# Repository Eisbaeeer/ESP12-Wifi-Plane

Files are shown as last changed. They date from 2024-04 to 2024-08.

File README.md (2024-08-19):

# VIMANA-STEM-LIGHT
The LIGHT version works with the prior ESP12E/ESP12F or other ESP8266 controllers.
This project is a fork without the need of N76E003. The main features is to use the controls of the new app to control two motors and servos.
You can use the unused ports to controll additional servos (not yet implemented).
If you need more, feel free to contribute.
Thank you to Ravi for his work.

You will find the Anrdoid App in the folder Andorid.

The Original Github repo for VIMANA2 Opensource Flightcontroller Board for Tiny Smartphone controlled Air plane and other moving/flying/floating things you will find on following links.
<br>Suitable for STEM Education<br>
Project Documentation : https://hackaday.io/project/190462-vimana-stem-for-all <br>
Youtube Playlist : https://www.youtube.com/playlist?list=PL6rHZ-FYvZtEZ2F3nPtqbe_Y3SMQ8Gjly <br>

## Features
- fully compatible to the first release of Ravis hardware
- supports two motors
- sending RSSI to mobile device
- sending battery voltage of receiver to mobile device
- calibrate motors
- update firmware via OTA http://192.168.43.42/update

## Schematic

| Board Pins | | Device Pin | Device Name | 
|---|-----|---|---|
| GPIO 04 | G | Gain | Motor right Si2302DS | 
| GPIO 05 | G | Gain | Motor left Si2302DS | 

## Folders

- CAD --> Plane cutouts for laser or cnc or by hand and pdf paper  
- Gerber --> Gerber files for PCB   
- src --> Source files for Platformio

## Flashing firmware

To flash the board, use UART to USB adapter. Do it in this step´s to enable flashing mode of ESP
1. Connect the pins to the UART adapter (GND, TX, RX)   
2. Connect E-pin to GND
3. Plug in the battery
4. Flash the ESP

## Updating firmware

The firmware includes OTA (Over-The-Air Update).
You can easily upload the compiled firmware file (firmware.bin) via web-browser.
Connect to the Wifi accesspoint of the plane, open the browser and type in the following url.
http://192.168.43.42/update

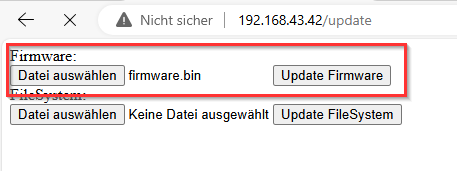
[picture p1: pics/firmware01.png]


Click on select file and upload the firmware (this takes some seconds). The click on Update Firmware.

## ToDo
- adding pins D1 (GPIO5), D2 (GPIO4), GND, VCC  (for future use of MPU6050)
- adding pins GPIO12, GND, VCC (Servo elevator)
- adding pins GPIO13, GND, VCC (Servo ruder)

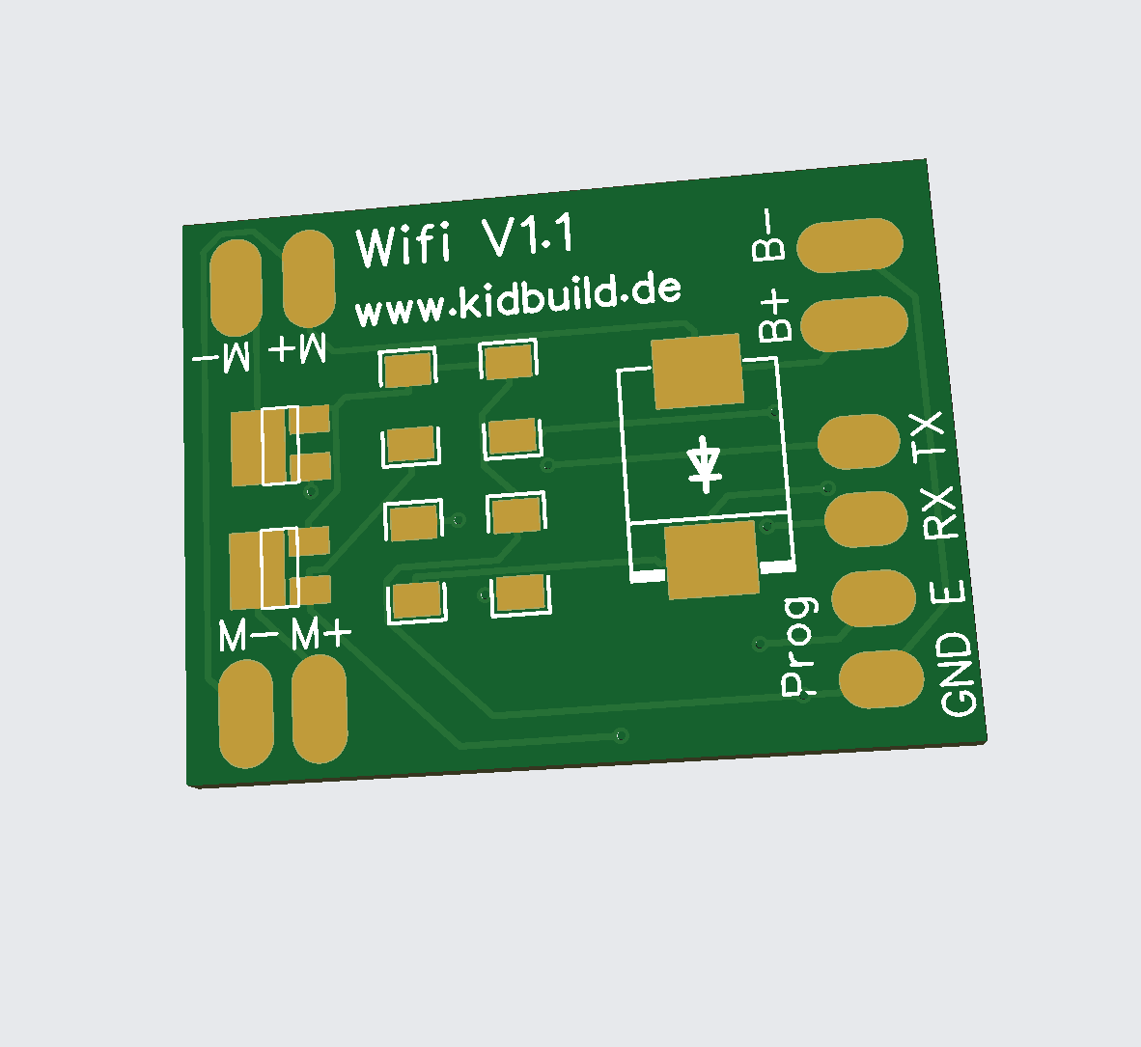
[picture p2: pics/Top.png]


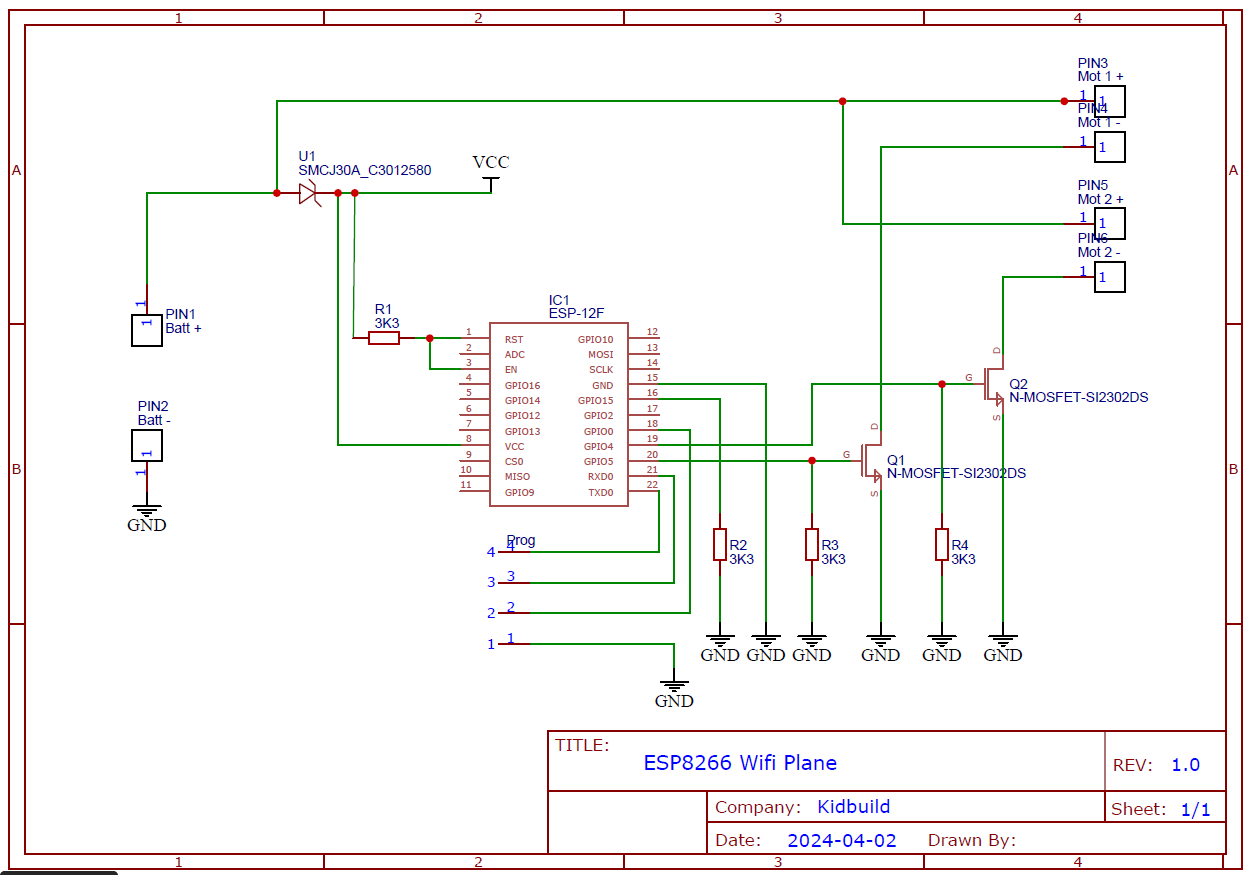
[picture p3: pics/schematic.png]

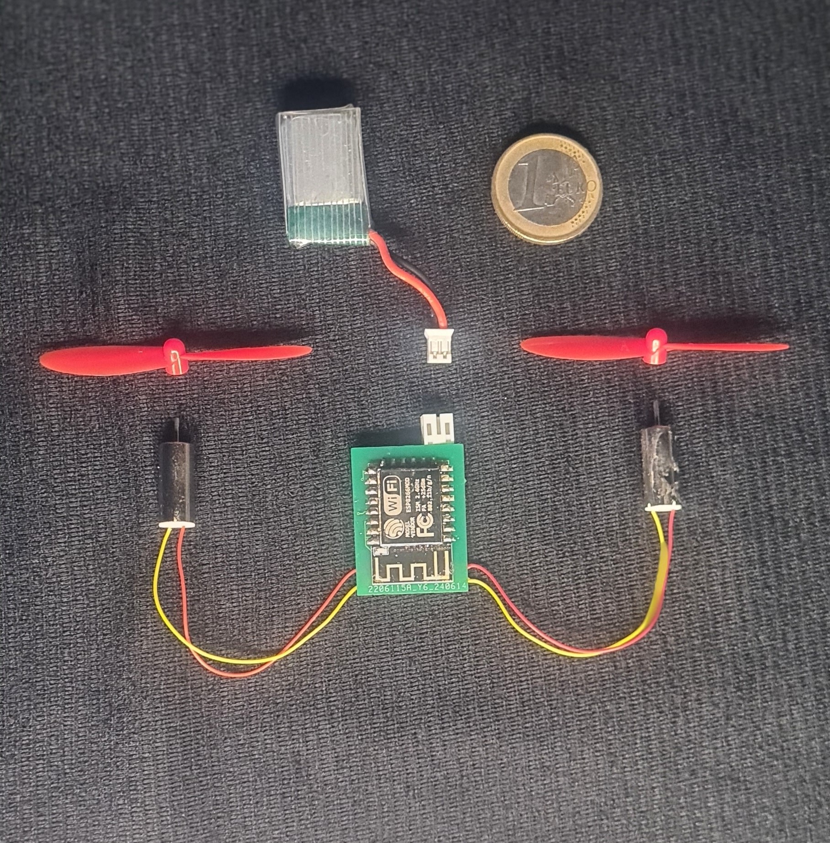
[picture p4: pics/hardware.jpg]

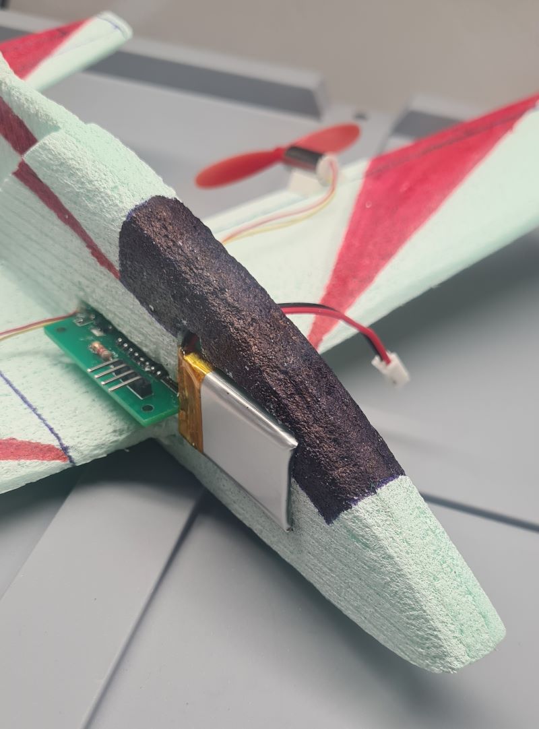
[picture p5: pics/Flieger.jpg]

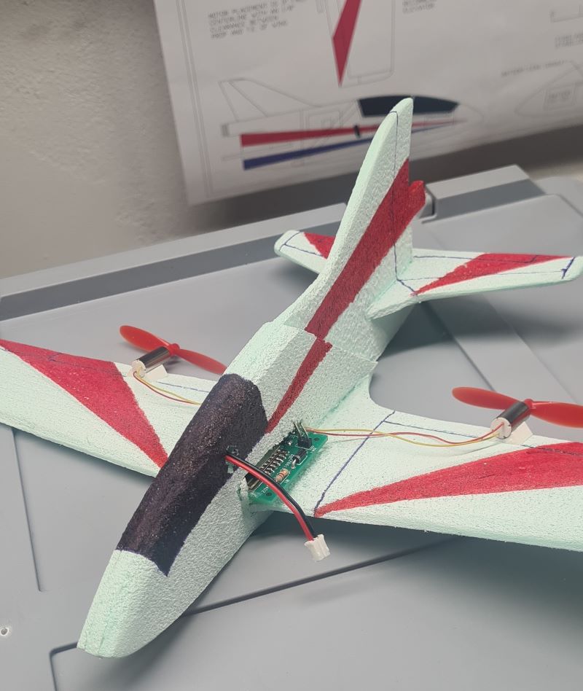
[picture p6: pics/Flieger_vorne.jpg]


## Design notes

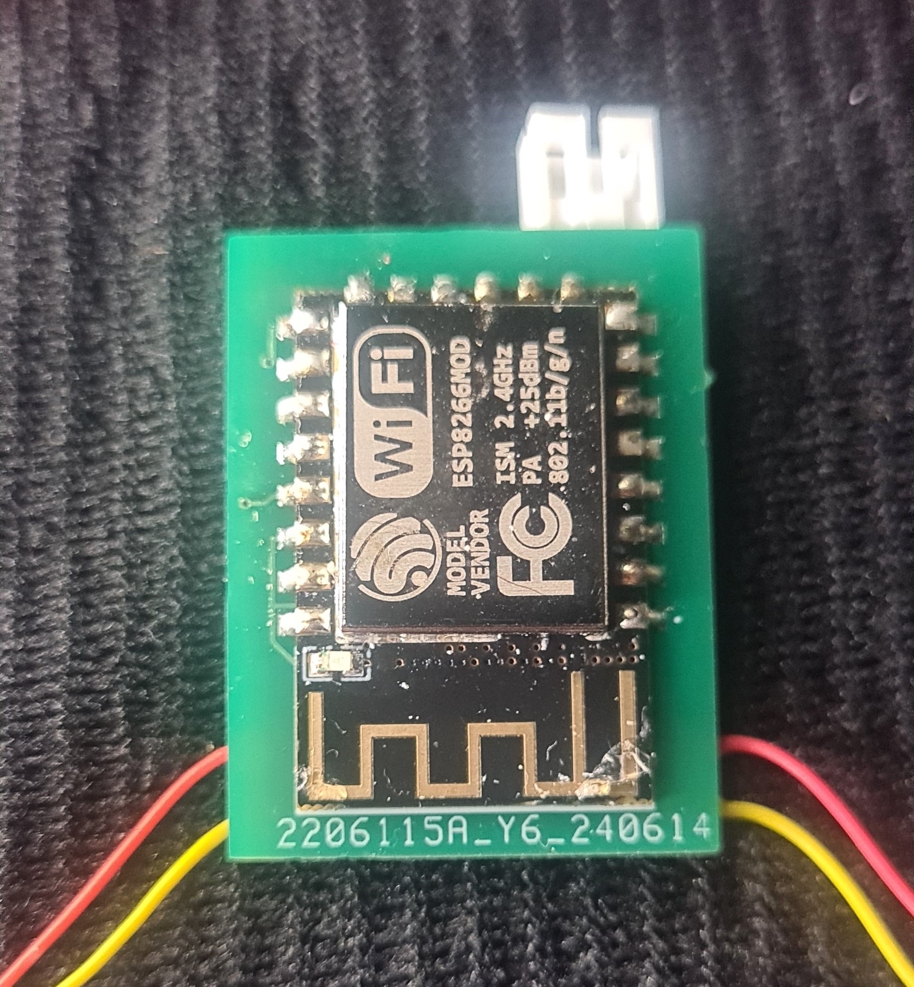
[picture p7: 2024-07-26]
pics/bottom.jpg

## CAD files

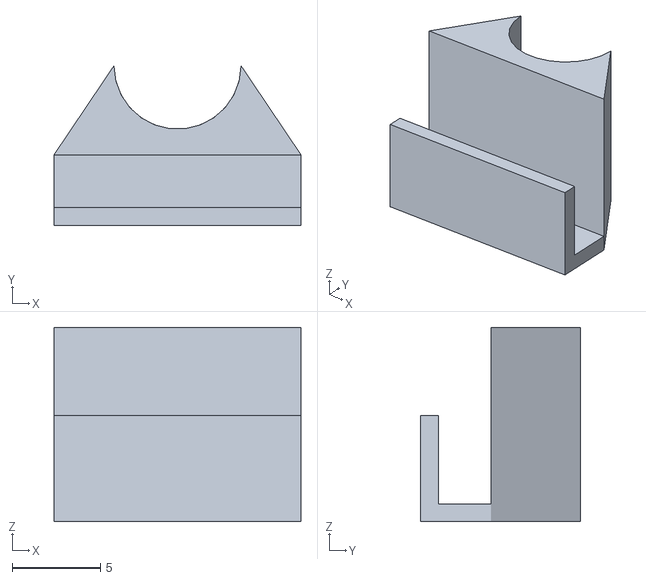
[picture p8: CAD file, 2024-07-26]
CAD/Motorblock_3mm_Depron.stl
14.0 x 9.05 x 11.0

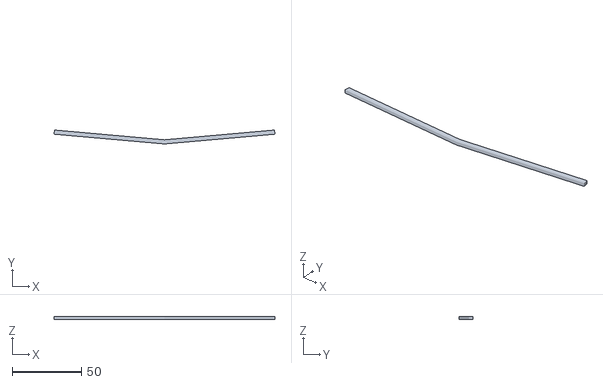
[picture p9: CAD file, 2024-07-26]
CAD/FluegelWinkel_3mm_Depron.stl
159.4 x 10.0 x 2.00

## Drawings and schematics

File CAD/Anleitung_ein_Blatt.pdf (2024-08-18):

# Wifi Controlled Park Flyer

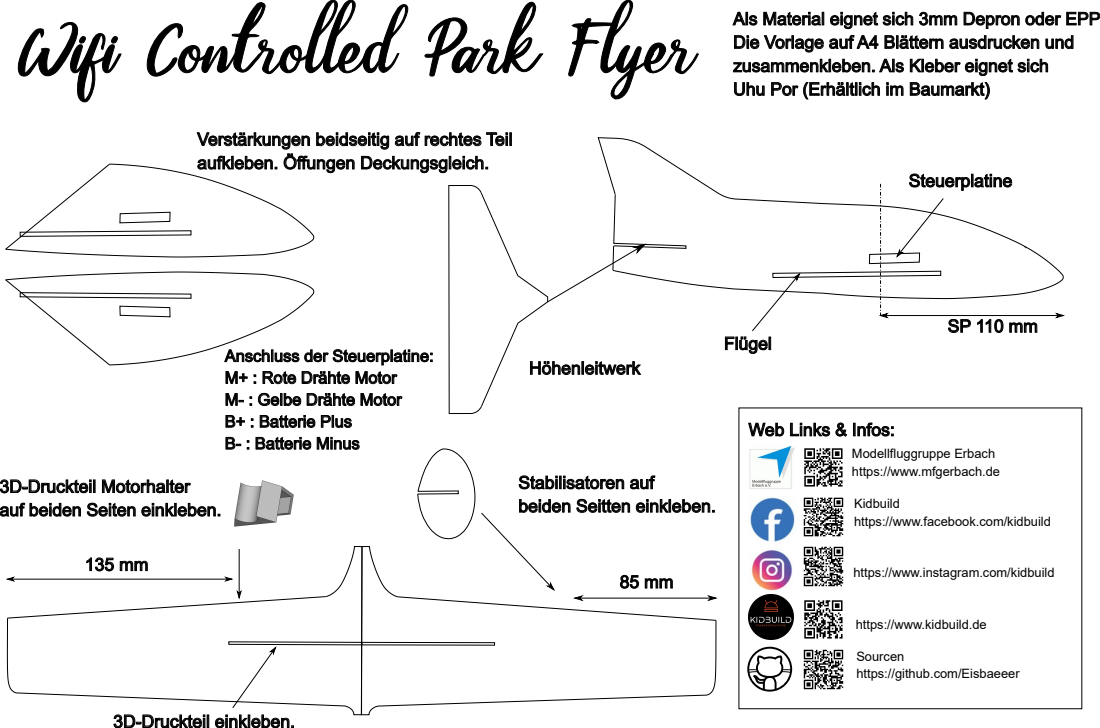
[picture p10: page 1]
Flügel; Höhenleitwerk; 3D-Druckteil einkleben.; Steuerplatine

Als Material eignet sich 3mm Depron oder EPP
Die Vorlage auf A4 Blättern ausdrucken und
zusammenkleben. Als Kleber eignet sich
Uhu Por (Erhältlich im Baumarkt)

Verstärkungen beidseitig auf rechtes Teil
aufkleben. Öffungen Deckungsgleich.

Anschluss der Steuerplatine:
M+ : Rote Drähte Motor
M- : Gelbe Drähte Motor
B+ : Batterie Plus
B- : Batterie Minus

Web Links & Infos:

Modellfluggruppe Erbach
https://www.mfgerbach.de

Stabilisatoren auf
beiden Seitten einkleben.

3D-Druckteil Motorhalter
auf beiden Seiten einkleben.

Kidbuild
https://www.facebook.com/kidbuild

https://www.instagram.com/kidbuild

https://www.kidbuild.de

Sourcen
https://github.com/Eisbaeeer

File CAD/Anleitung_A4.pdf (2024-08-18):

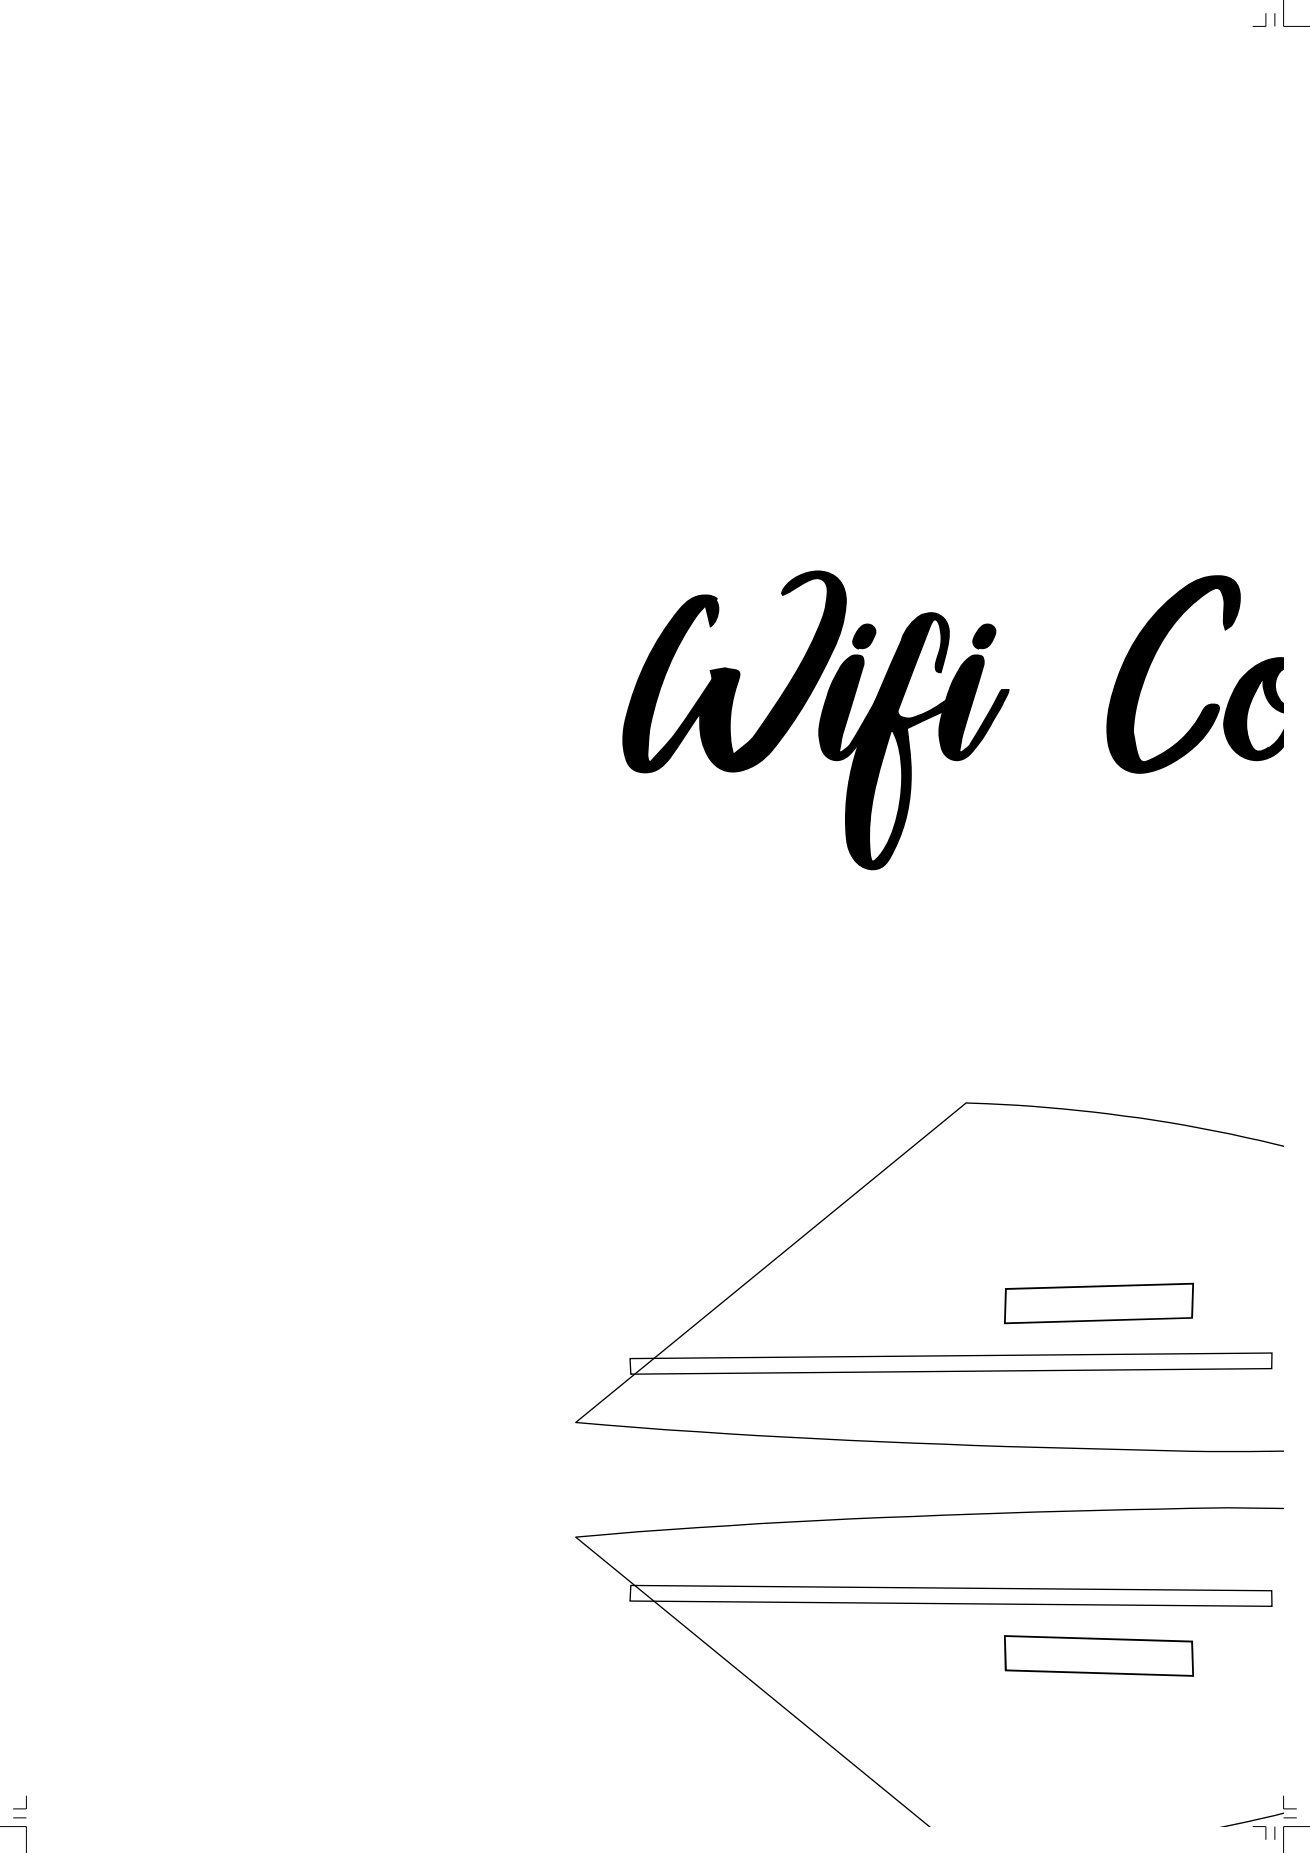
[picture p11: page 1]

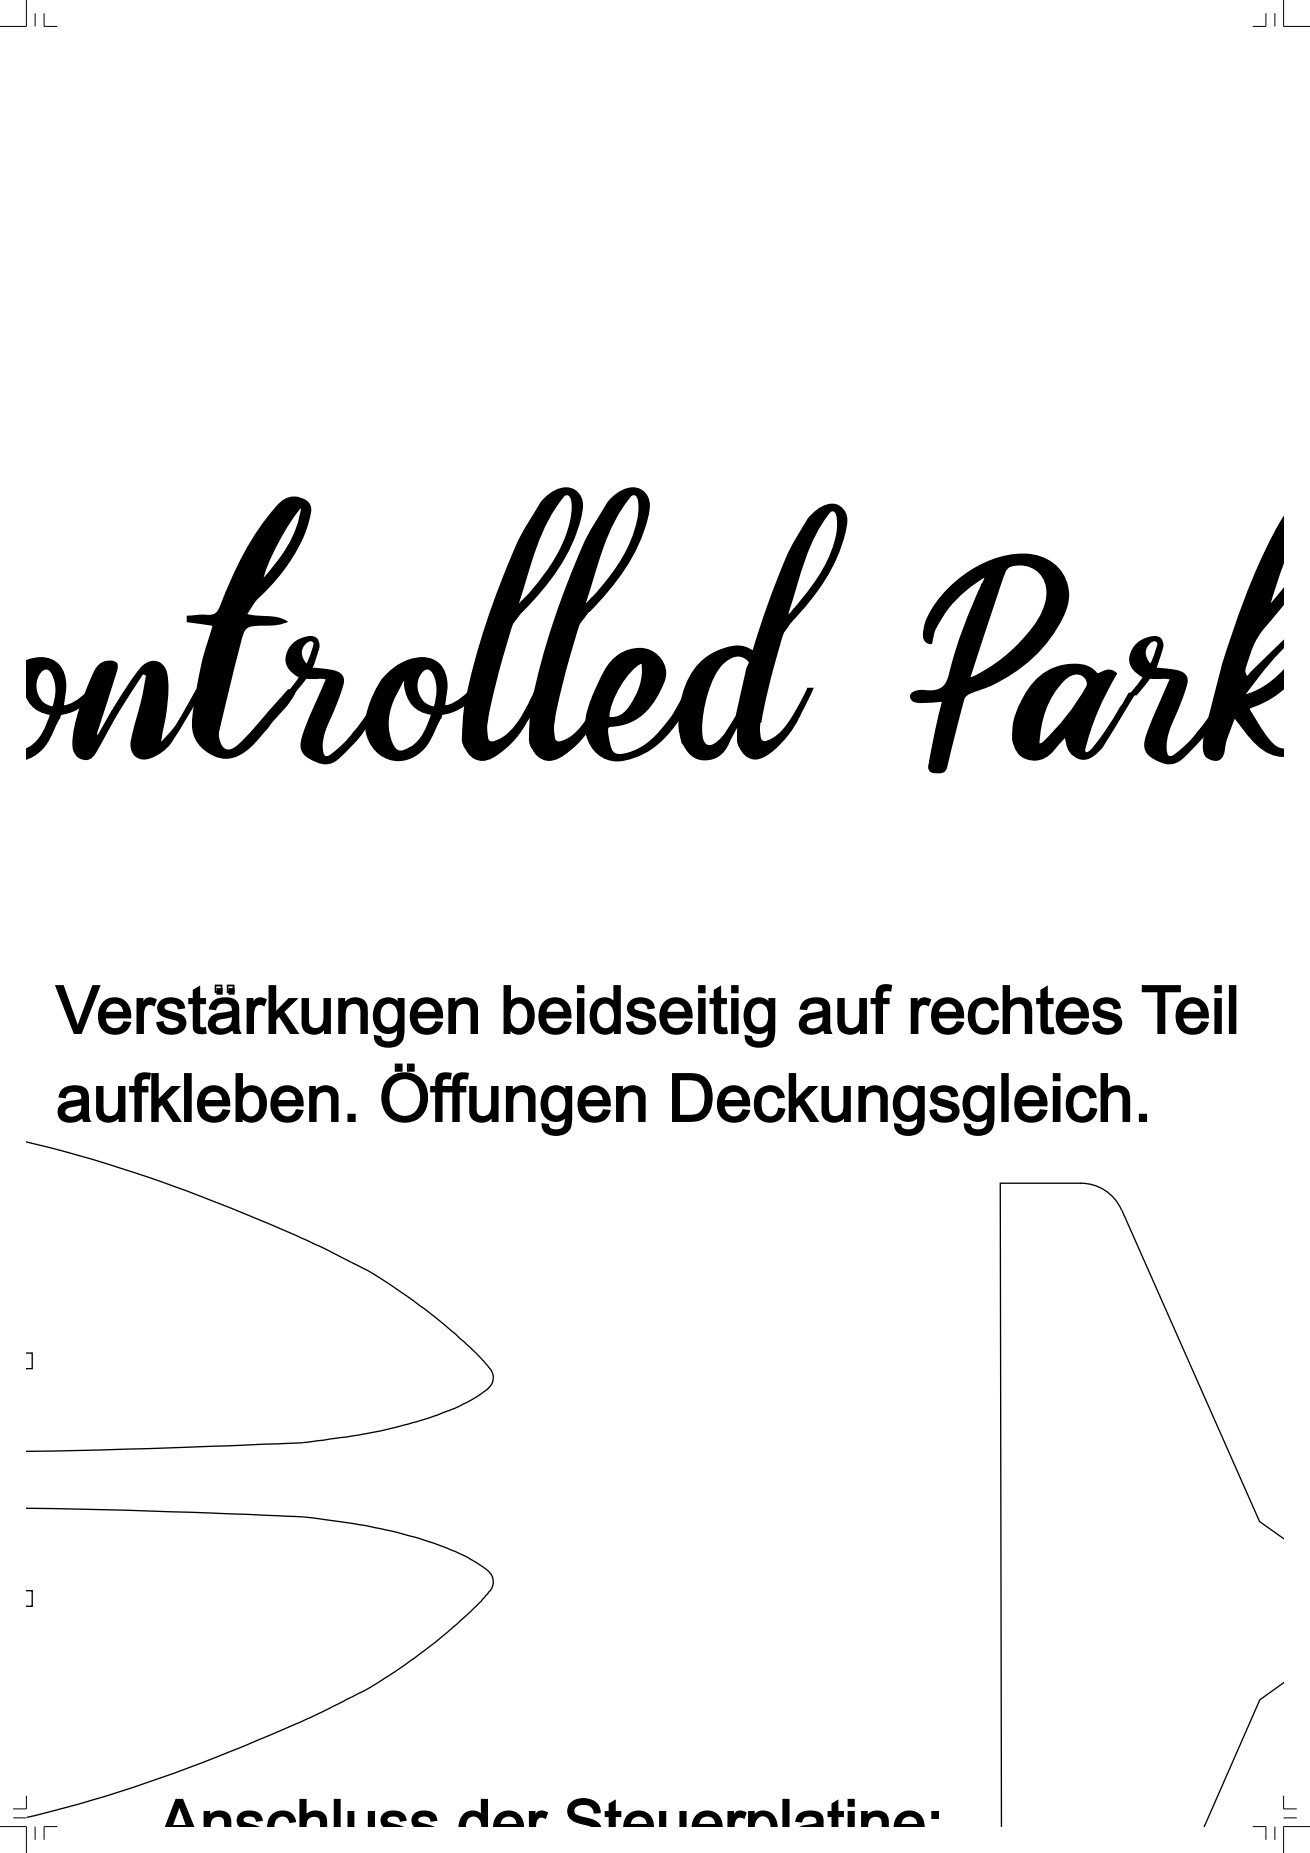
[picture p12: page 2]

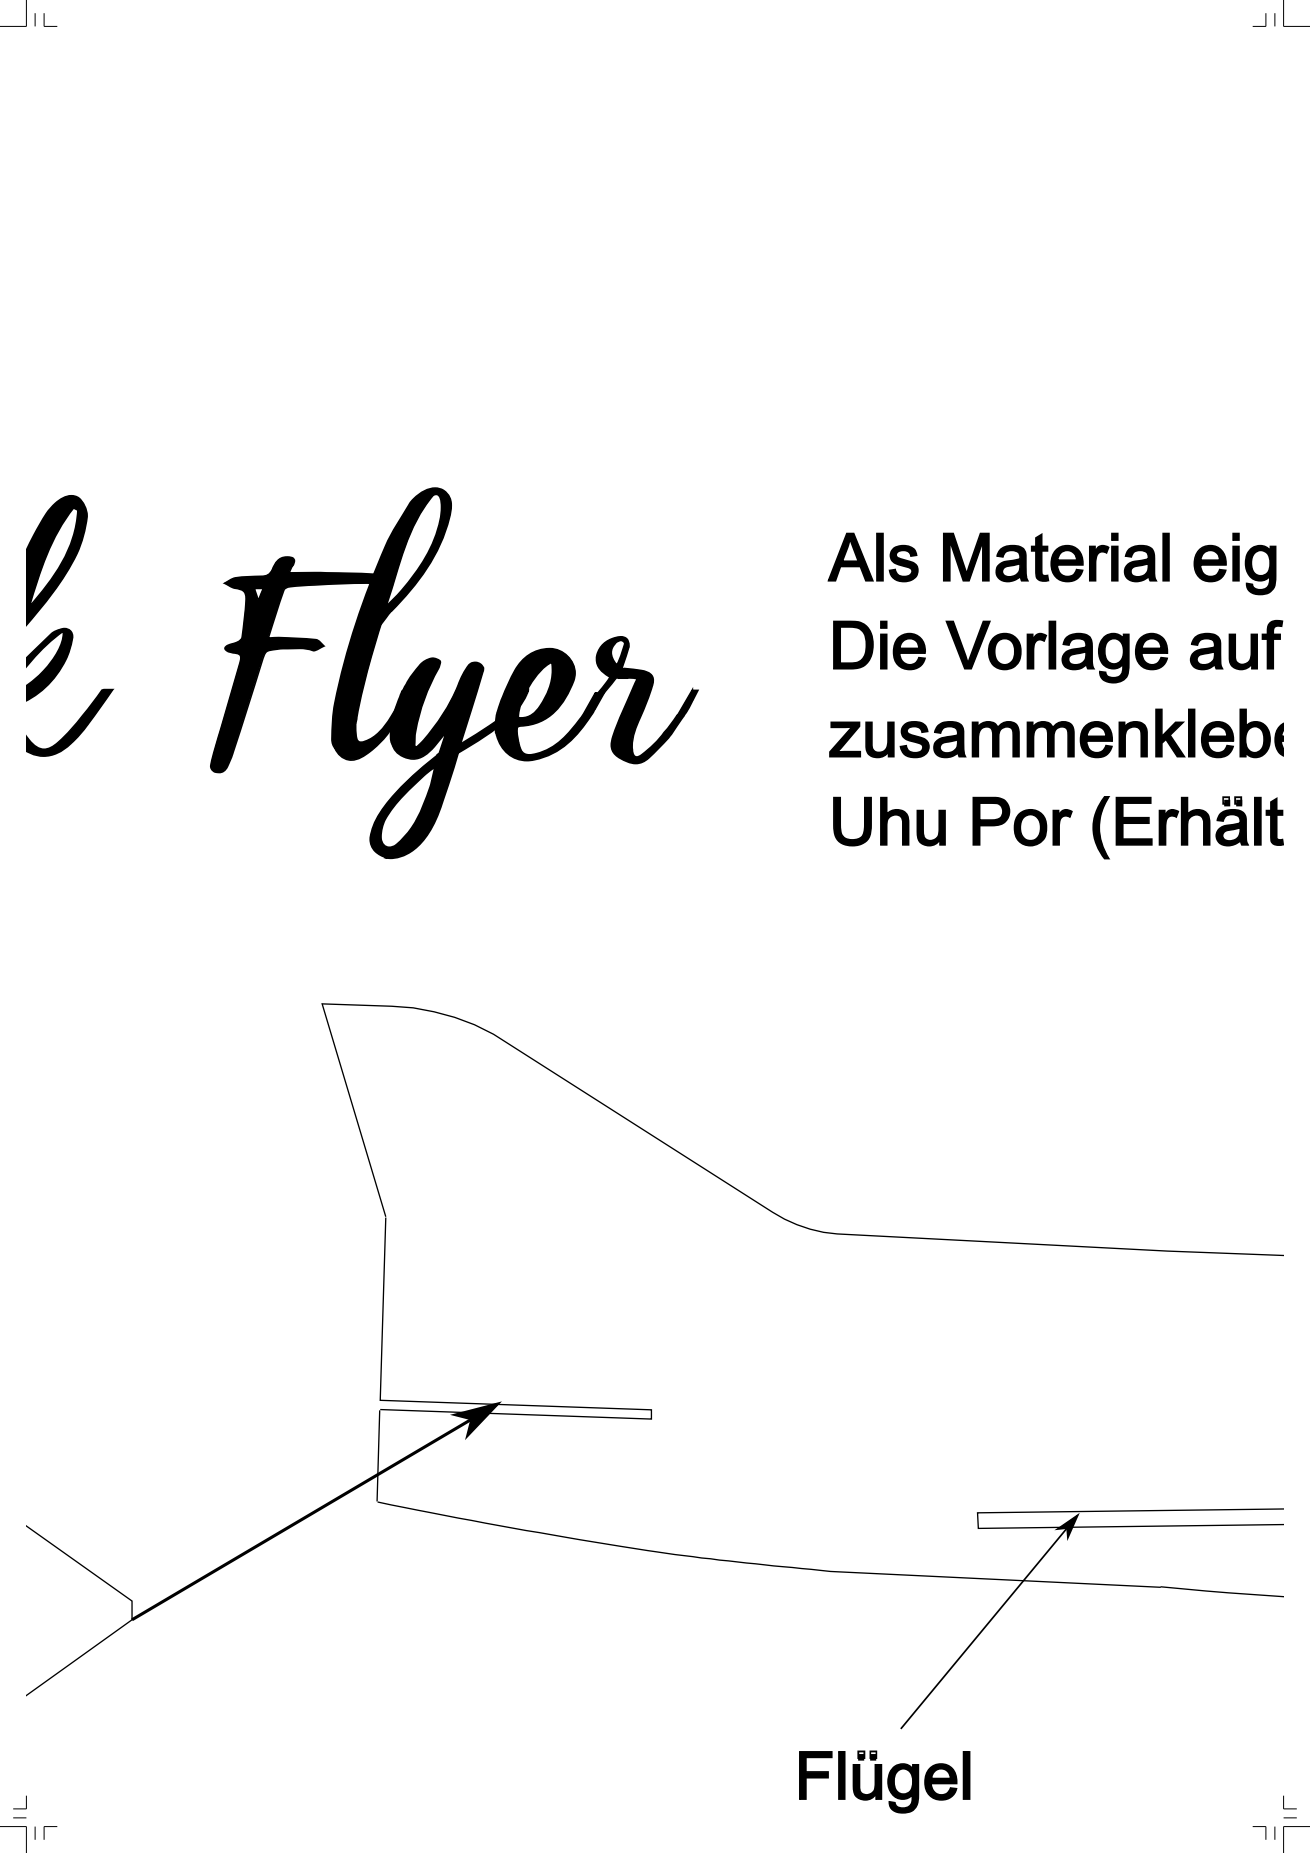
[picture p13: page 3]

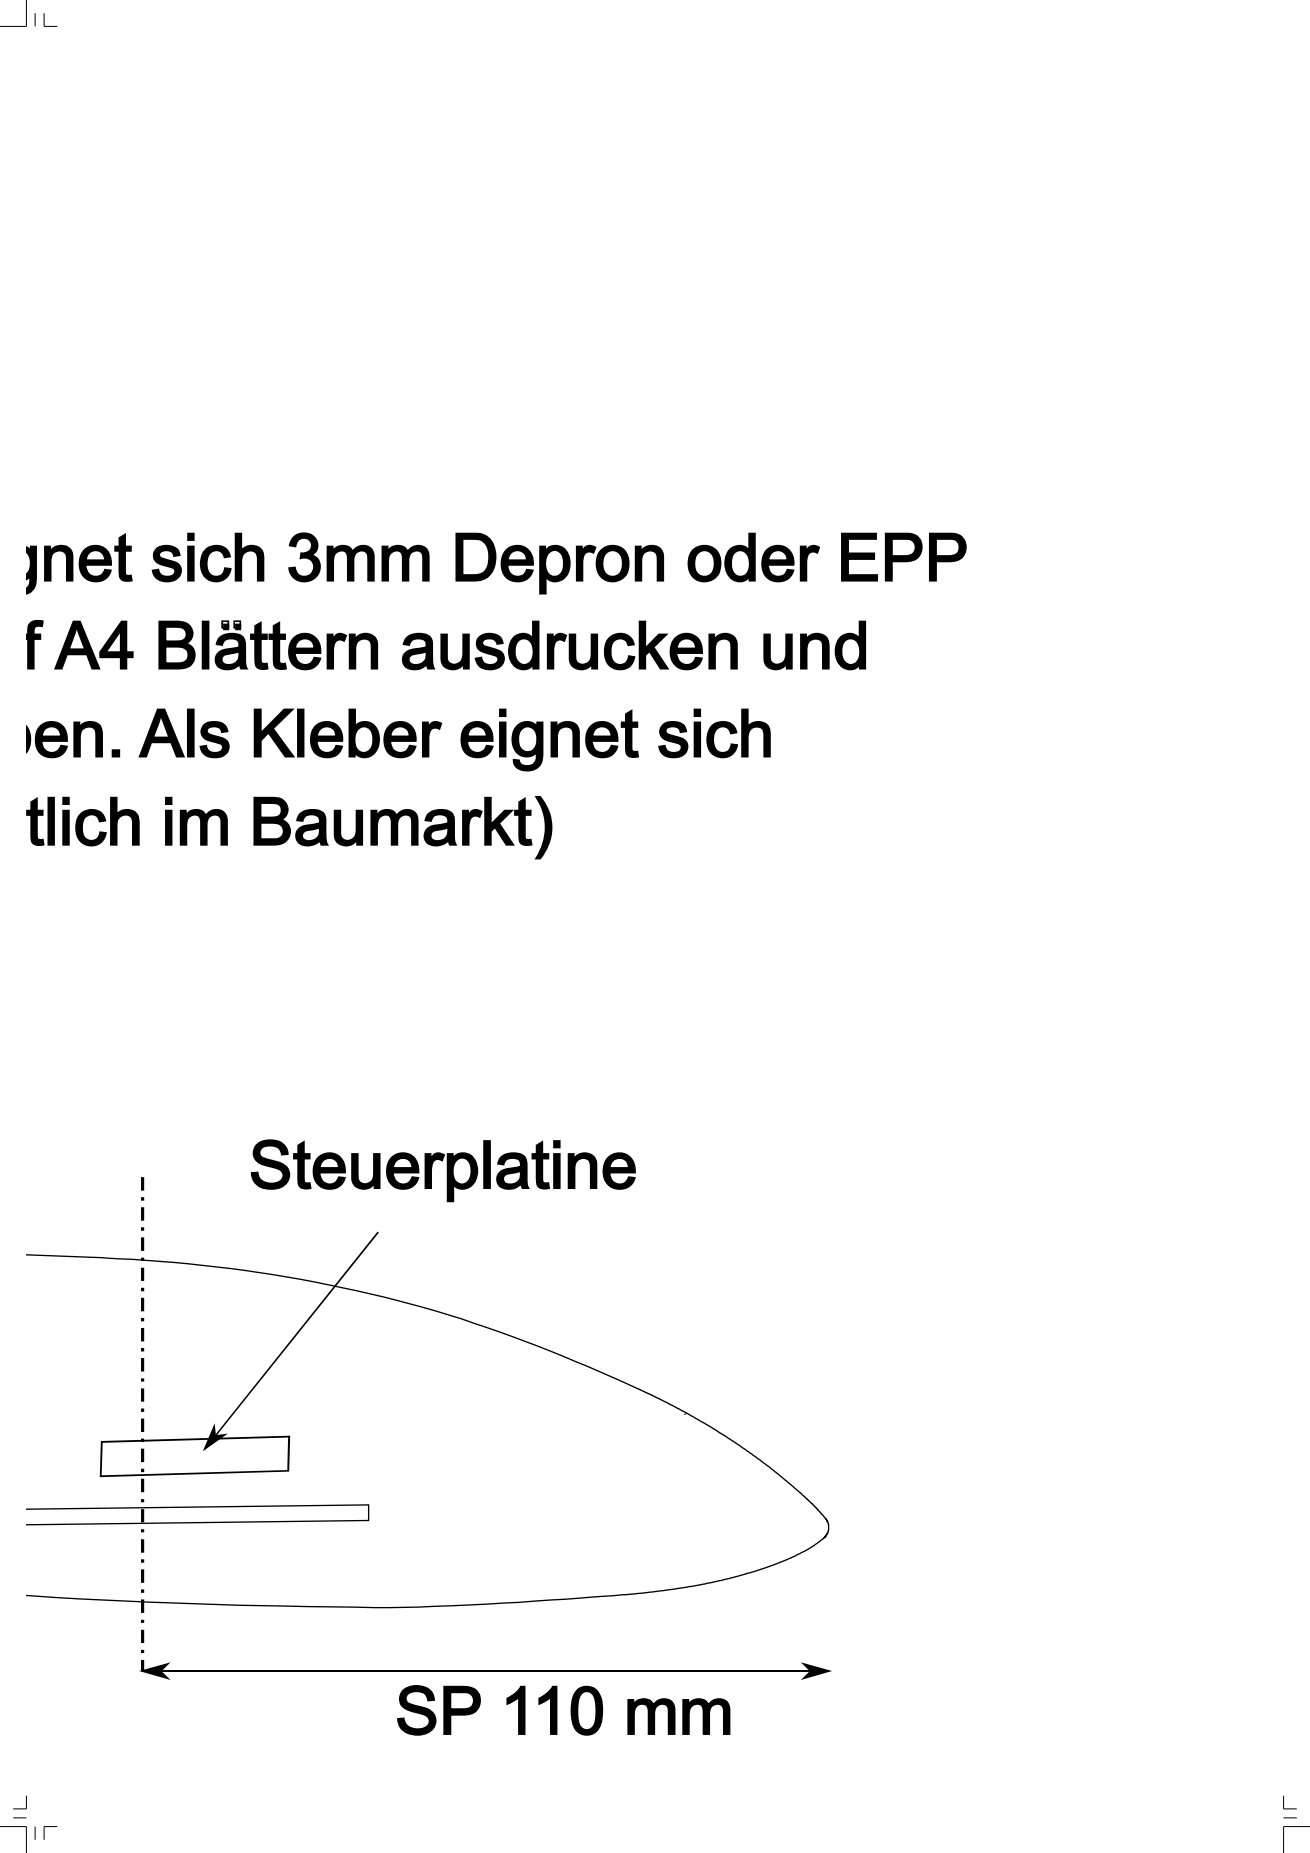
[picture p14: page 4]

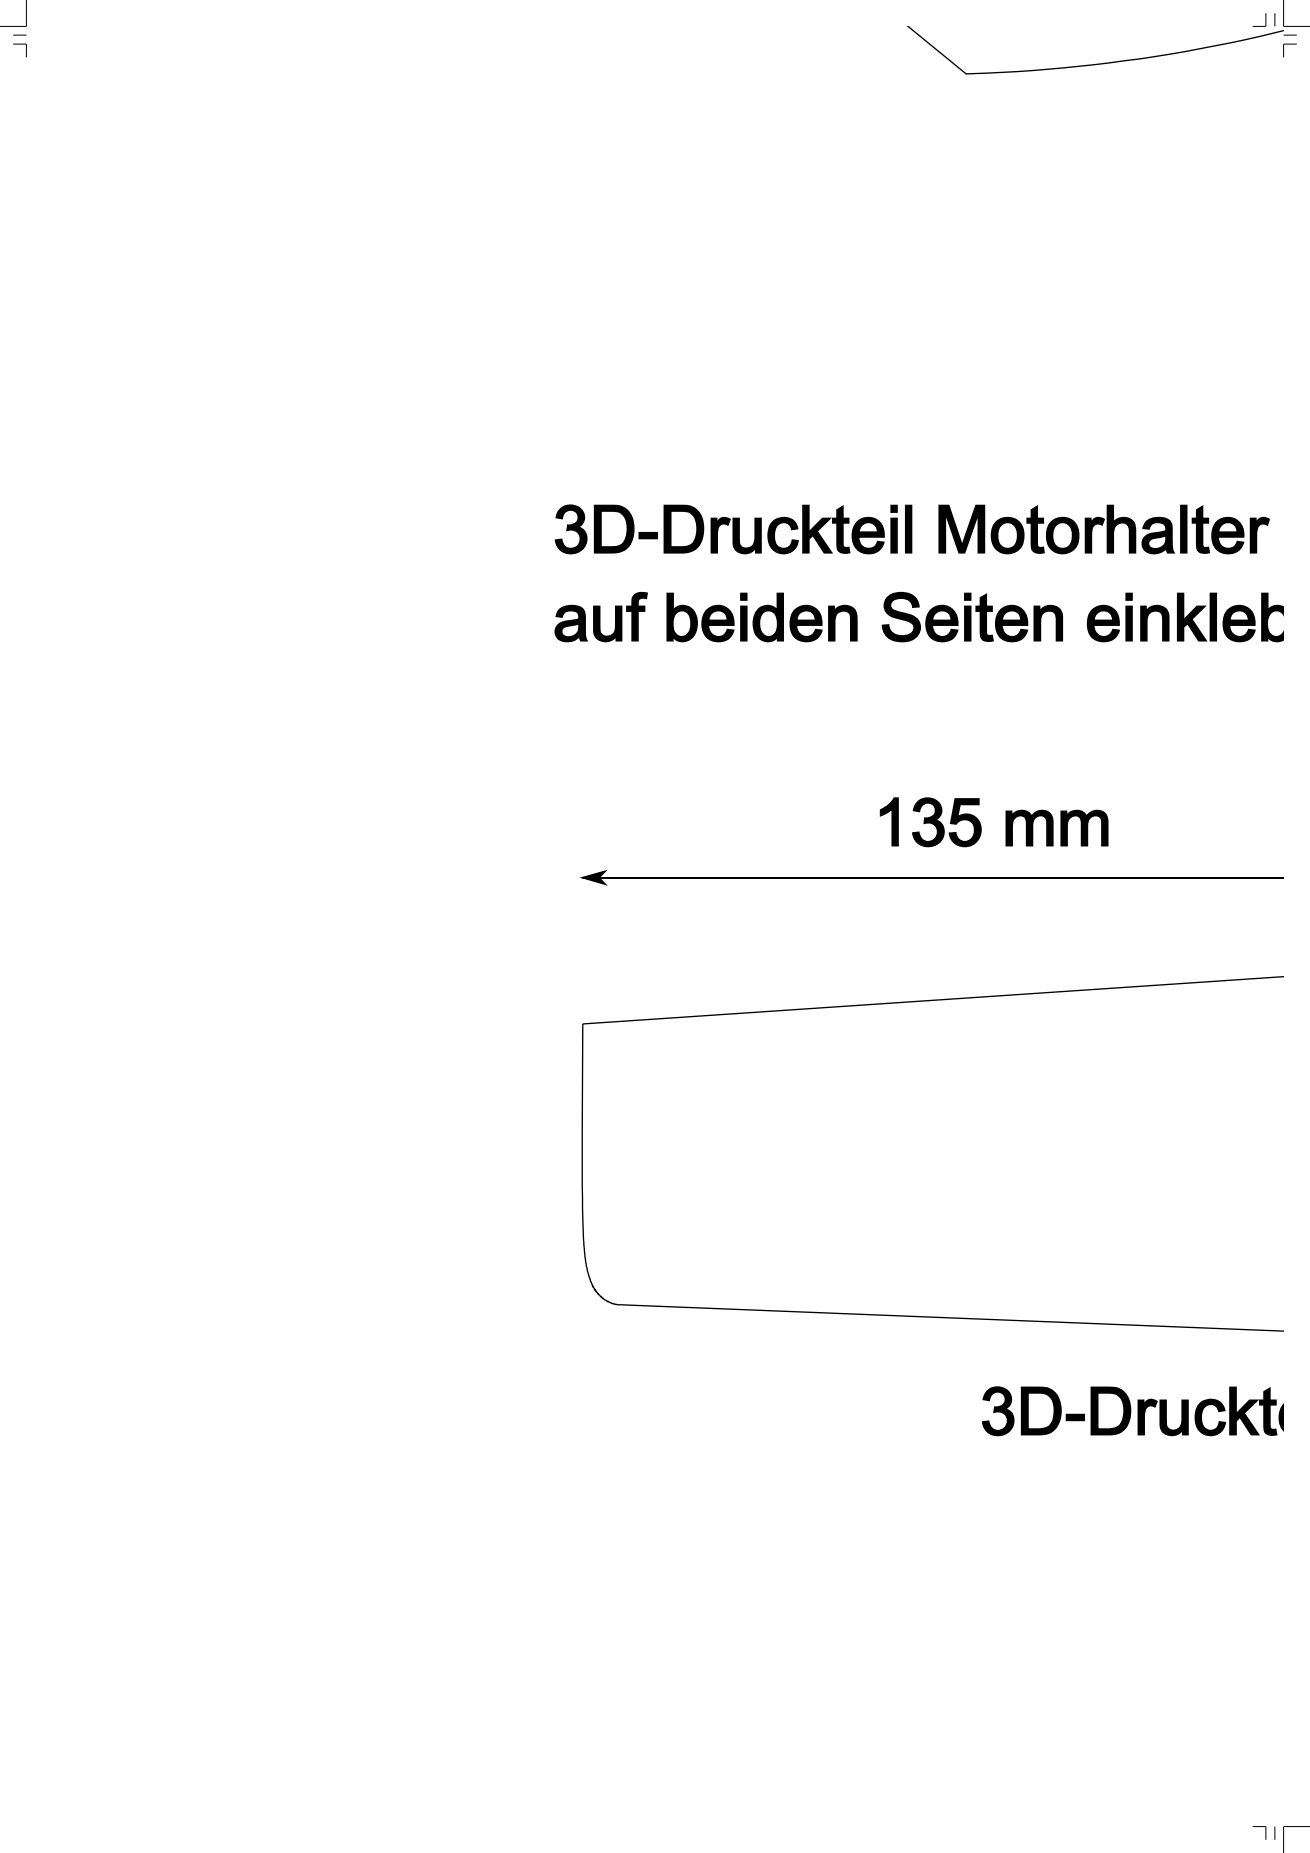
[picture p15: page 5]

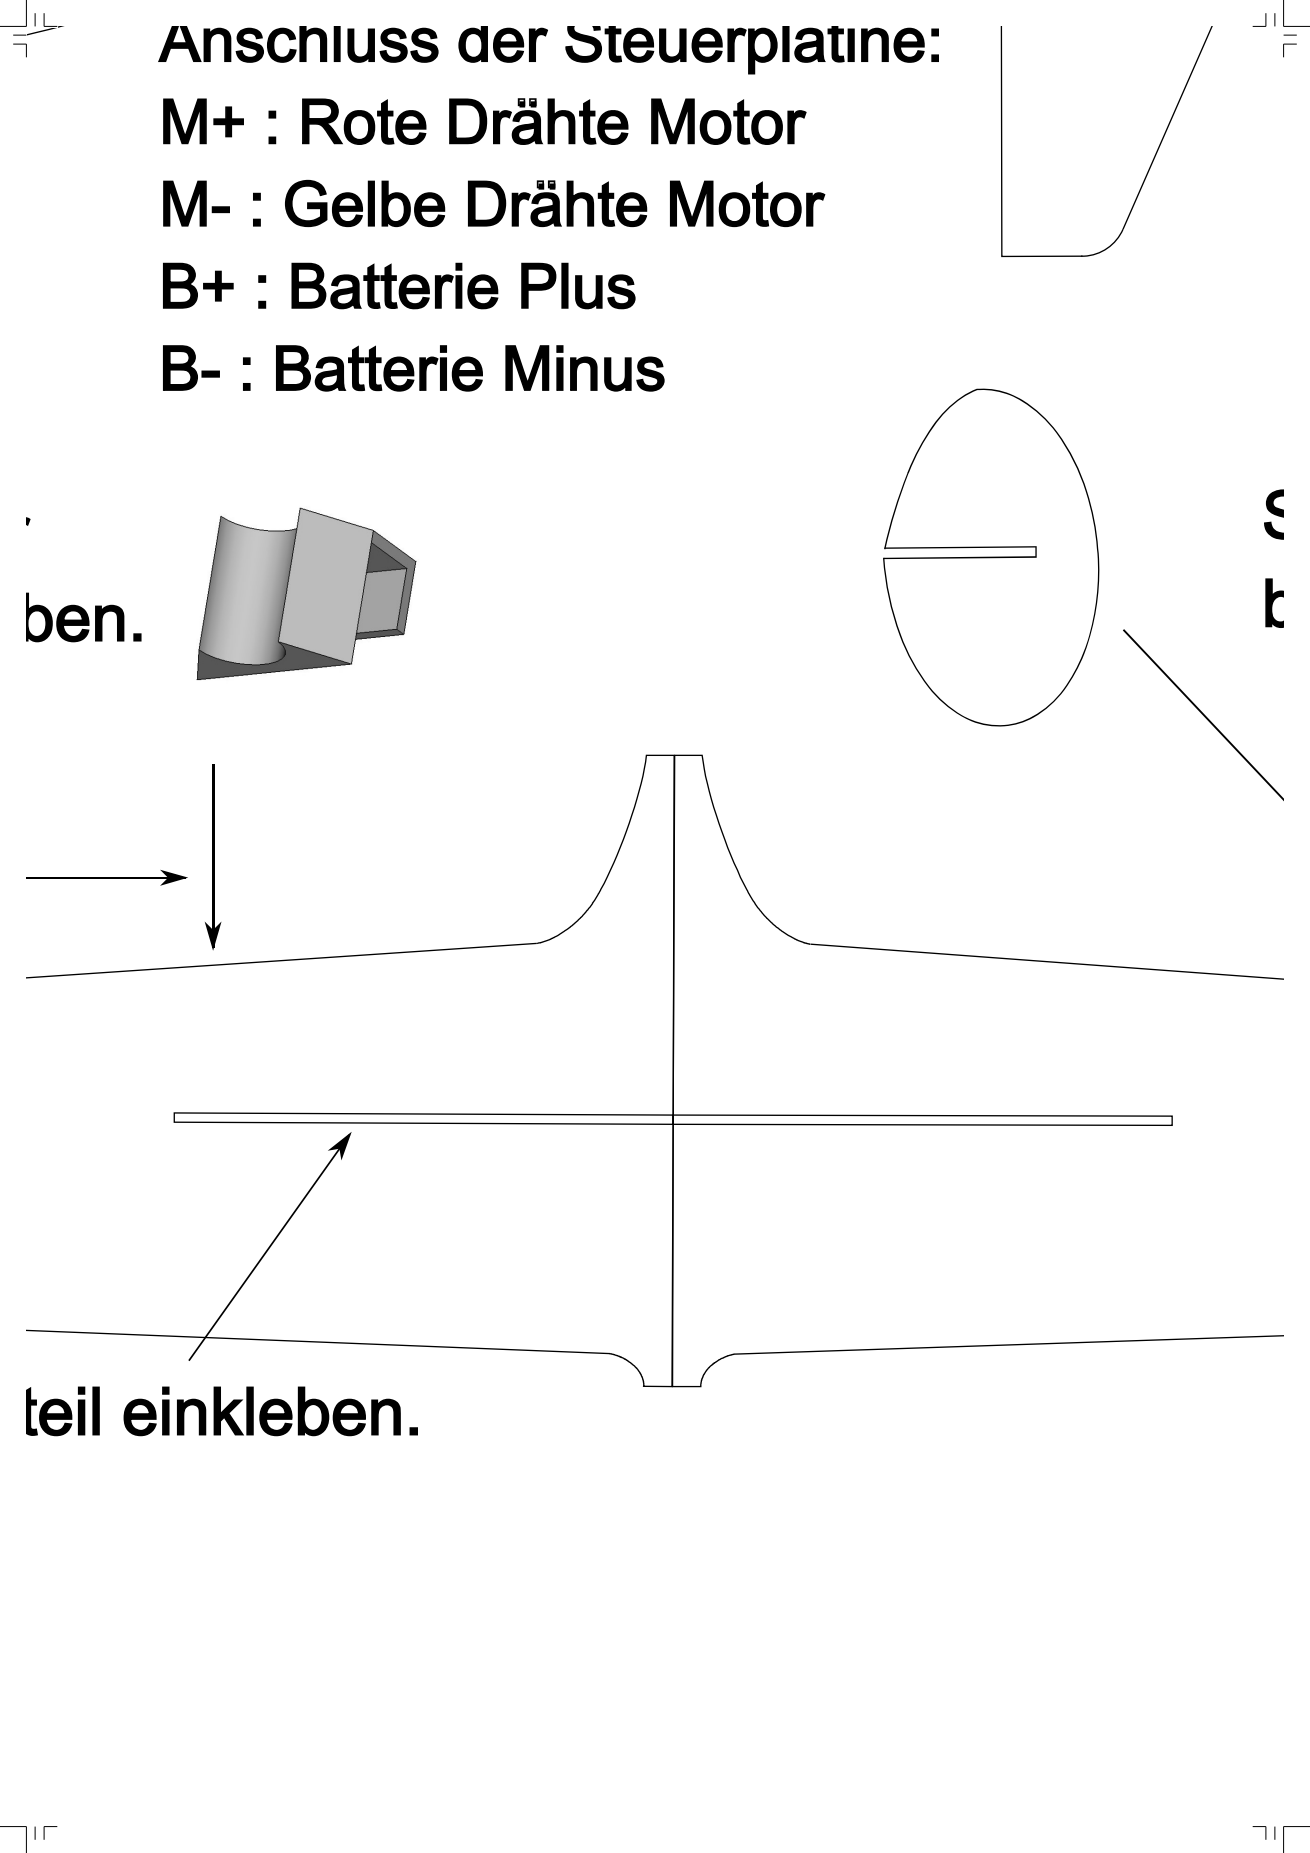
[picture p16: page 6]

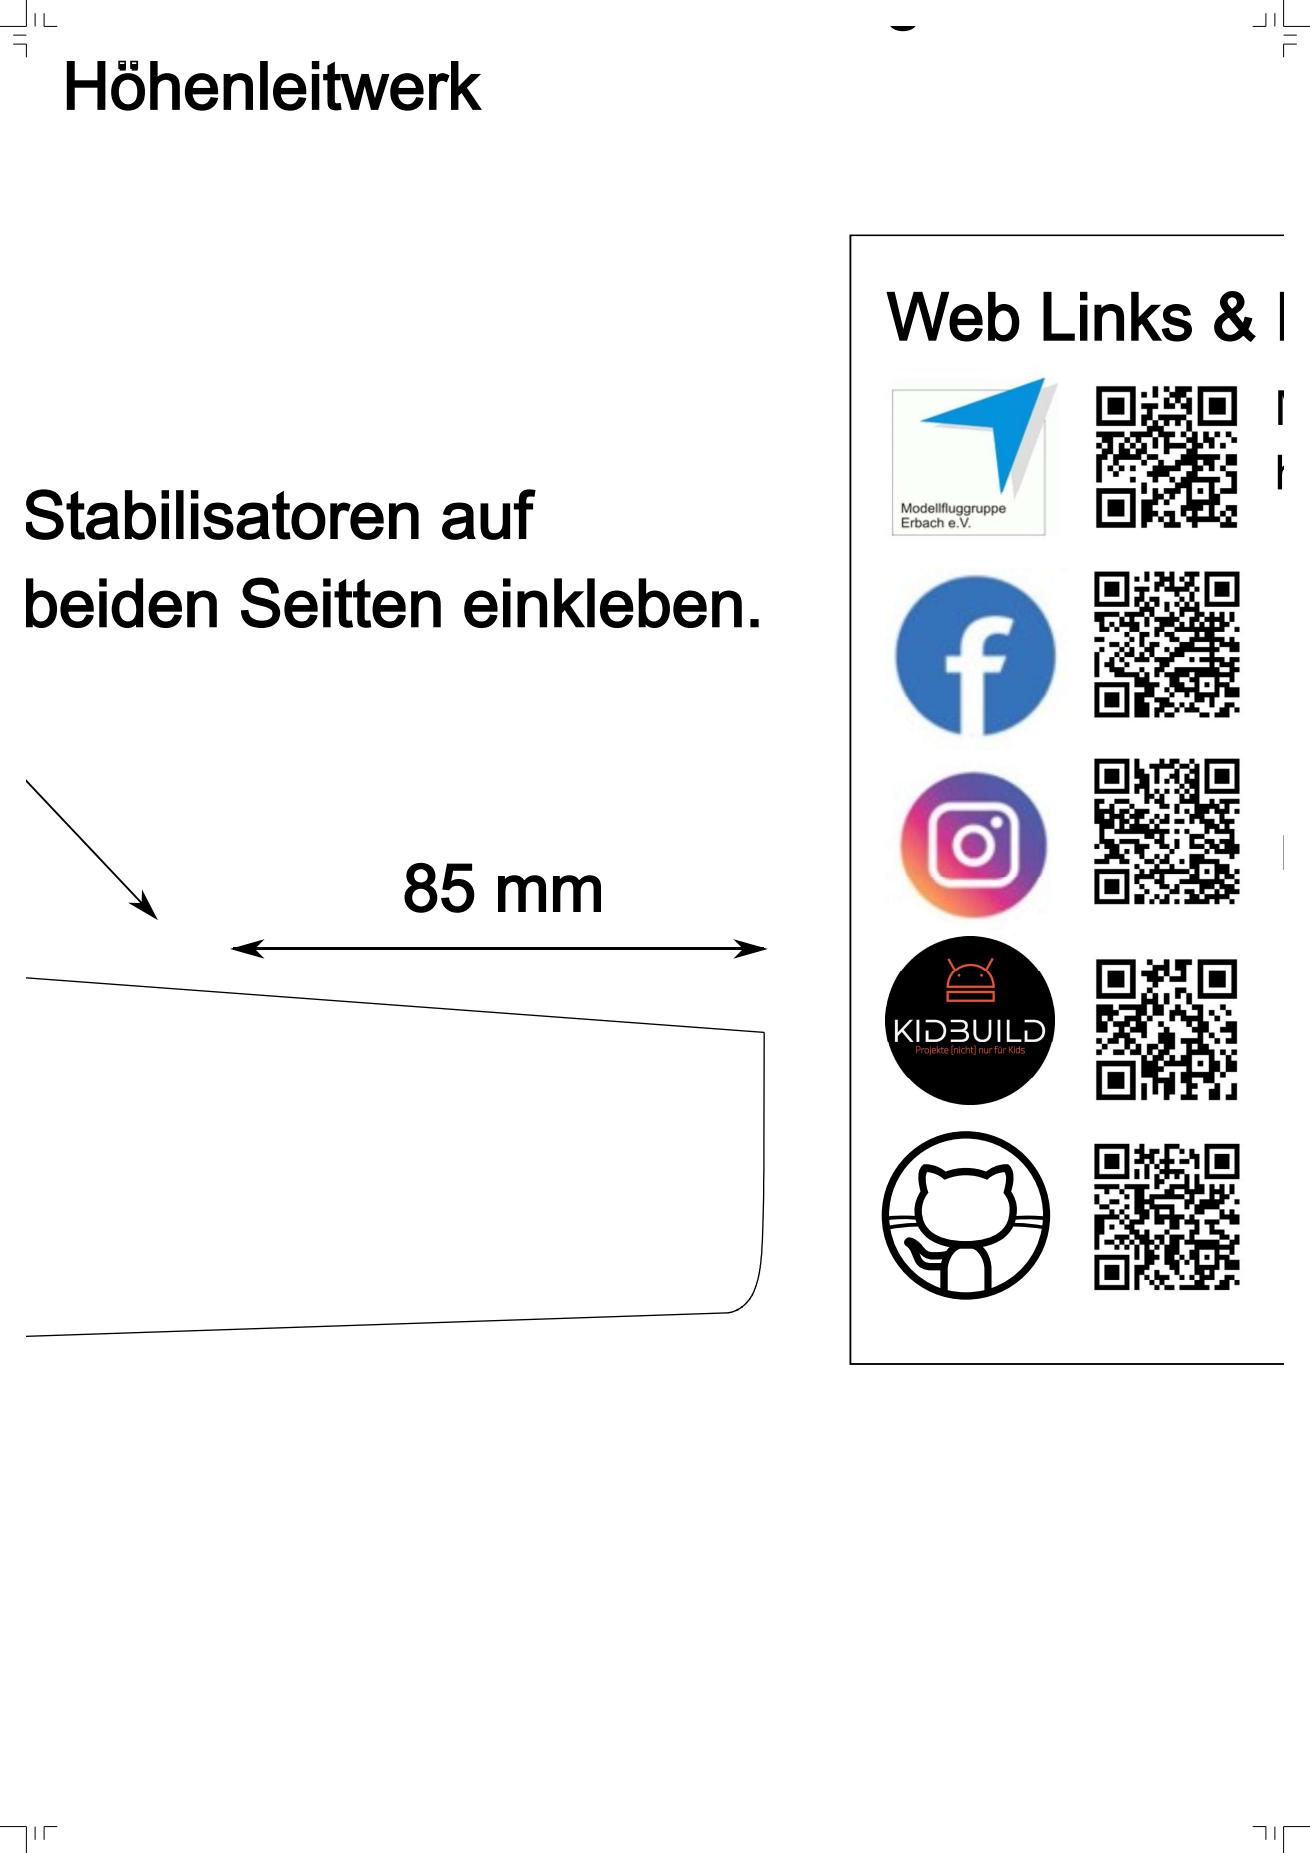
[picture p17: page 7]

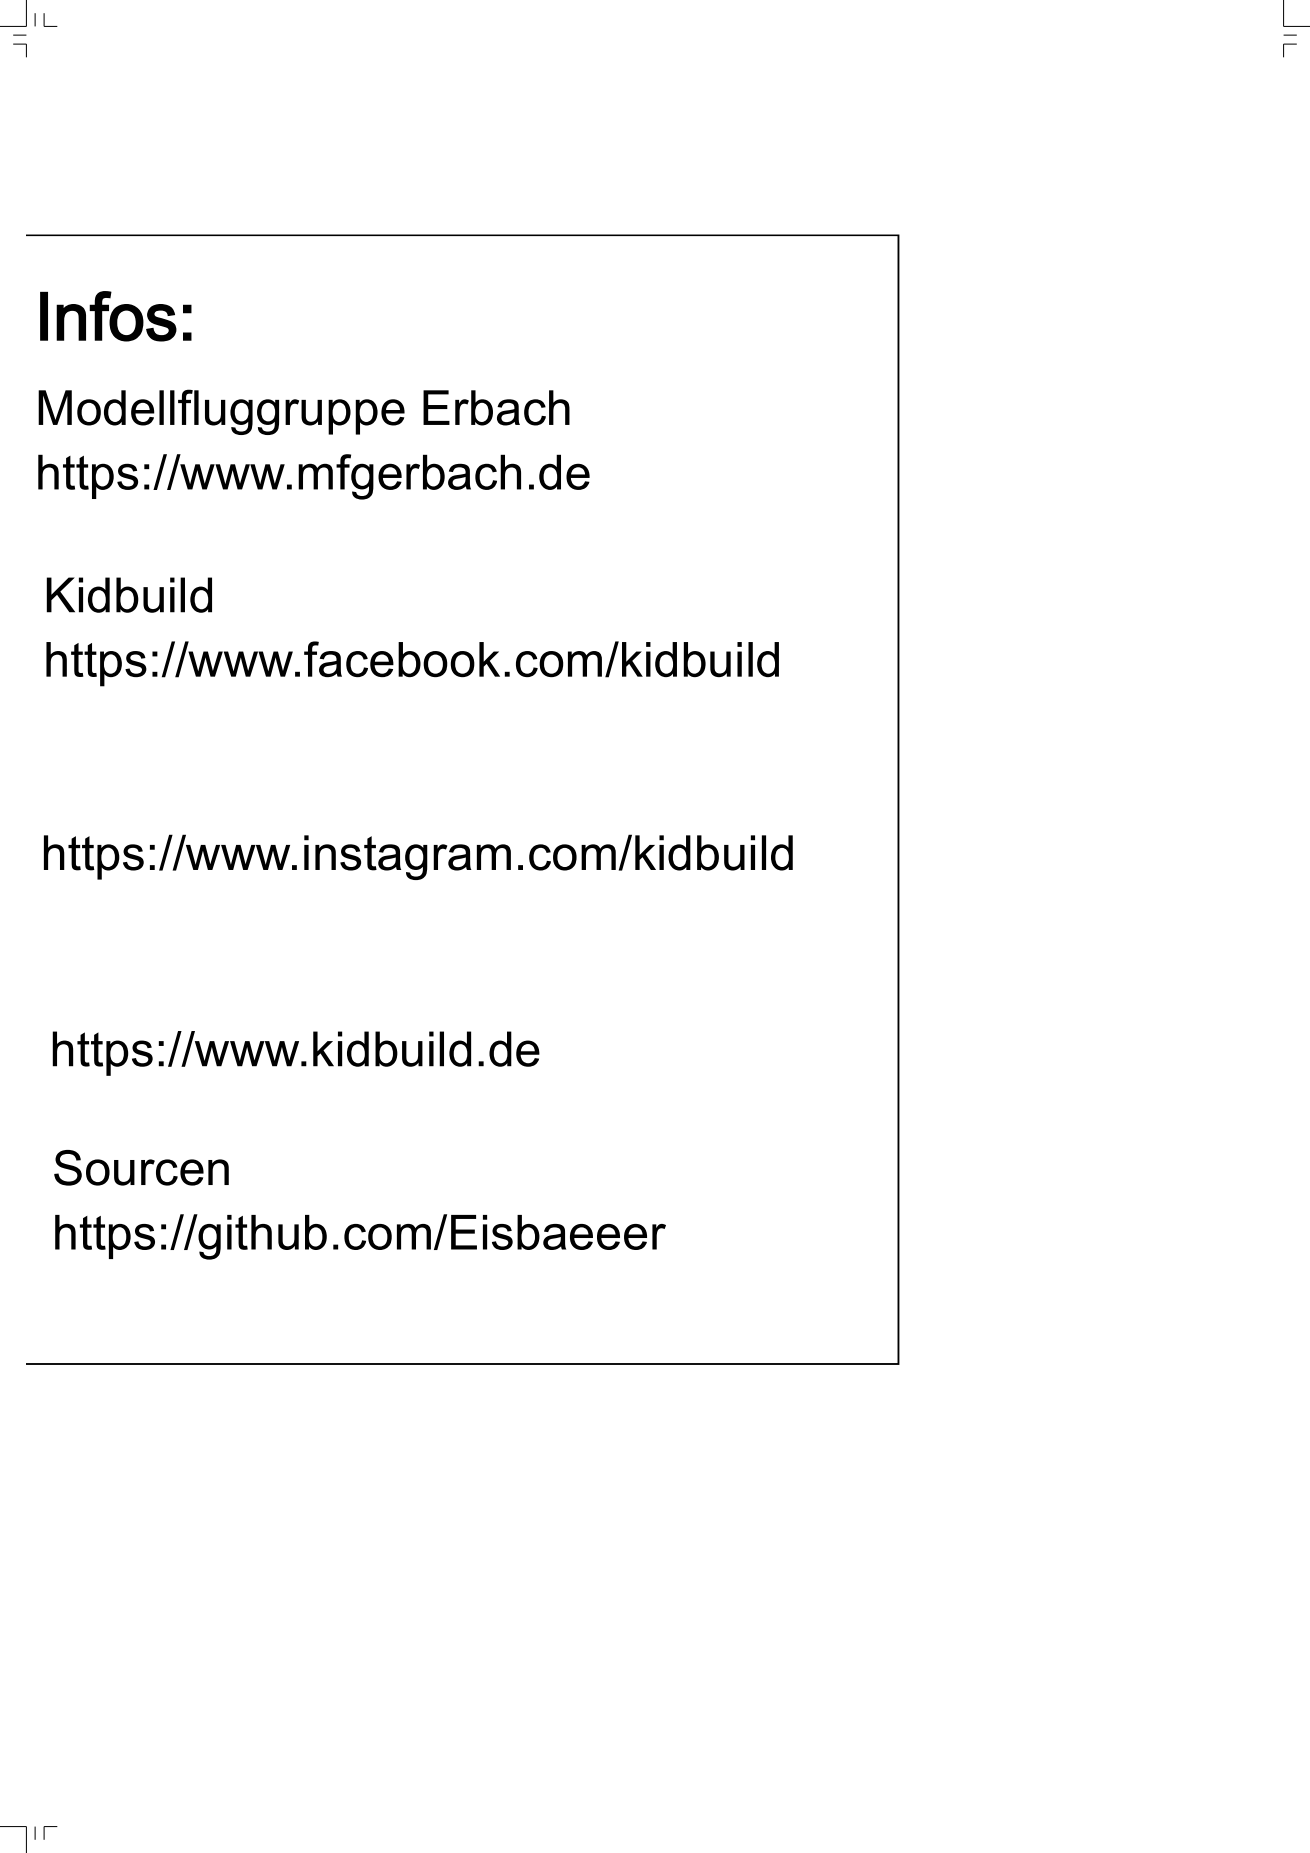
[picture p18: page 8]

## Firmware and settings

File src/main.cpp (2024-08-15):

#include <Arduino.h>

/**********************************************************************
 *  VIMANA2 ESP8266 based flight controller for STEM/STEAM Education
 *  Plane diff thrust 2-MOTOR 2-SERVO (NO IMU)
 *  Designed and developed by Ravi Butani 
 *  Contact : ravi.butani03@gmail.com
 *  Version 2 - April 2023
 *  Note : ESP8266WiFiAp.h changed max connection to 1 in SDK
 *  Note : Need N76E003 Slave MCU for ARM status and PWMs for Motor and SERVO drive
 *	Project Documentation : https://hackaday.io/project/190462-vimana-stem-for-all
 **********************************************************************
 *  20240405
 *  Lars Weimar
 *  Ported Firmware to using new APP with first project (only 2 motors)
 *  No N76E003 needed!
 *  Changed Analog Read to input voltage of module
 *
 *  20240406
 *  Lars Weimar
 *  Added OTA updates
 *  open http://192.168.43.42/update
 *
 *  20240725
 *  Added motor calibration
 * 
 *  20240815
 *  Changed OTA Update Software
 **********************************************************************/

#include <ESP8266WiFi.h>
#include <WiFiUdp.h> // used for UDP comms.
#include <EEPROM.h>
#include <ESP8266WiFi.h>
#include <WiFiClient.h>
#include <ESP8266WebServer.h>
#include <ESP8266HTTPUpdateServer.h>
#include <ESP8266mDNS.h>

unsigned long ota_progress_millis = 0;

#define DEBUGLED  // Uncomment this line to observe loop and rx pkt timing
//#define DEBUGSER  // Uncomment this line to get redable values of angle and rx pkt on serial terminal (note - N76E003 not understand this readings)

#define PID_LOOP_US  6000
#define L_MOTOR 5
#define R_MOTOR 4

unsigned int l_speed = 0;
unsigned int r_speed = 0;
unsigned int l_calibrate = 0;     // calibrate motor 0 to -128
unsigned int r_calibrate = 0;     // calibrate motor 0 to -128

#define DEBUG_LED     2  //D4  // Toggle when pkt received
#define DEBUG_LED2    16 //D0  // HIGH during calculation in loop
#define RESP_CNT_MAX  50

// OTA settings
ESP8266WebServer httpServer(80);
ESP8266HTTPUpdateServer httpUpdater;

WiFiUDP Udp;

//***UDP Variables***
unsigned int localUdpPort = 2390;

//*** Soft Ap variables ***
// fixed ip 192.168.43.42
IPAddress APlocal_IP(192, 168, 43, 42);
IPAddress APgateway(192, 168, 43, 42);
IPAddress APsubnet(255, 255, 255, 0);
uint16_t rxcount=0;

unsigned long microsold=0;

int16_t R_ch=128, P_ch=128, T_ch=0, Y_ch=128; 
unsigned char AUX_ch;
 
float R_in=0,R_set=0,R_out=0; 
int16_t mot1_final=0,mot2_final=0;
uint32_t loop_count=0;
uint32_t old_pkt_cnt=0, current_pkt_cnt=0;
uint8_t con_flag=0;
uint8_t debug_flag=0;
uint8_t ser_r,ser_p,ser_y;

void setup_hardware_wifi_ap(void);

// ======================== check for RX Packet ============================
unsigned int check_rx_pkt(int16_t& rch,int16_t& pch,int16_t& tch,int16_t& ych,unsigned char& auxch)
{
 int packetSize = Udp.parsePacket();
 char incomingPacket[12];
 char replyPacket[] = "OK1";
 if (packetSize)
 {
   // receive incoming UDP packets ToDO On Receive PID Request Caliberate Gyro and for 3second no packet received than motor off (if possible)
   int len = Udp.read(incomingPacket, 25);
   if (len > 8)
   {
    auxch = incomingPacket[0];
    if (((auxch & 0xB1) != 0x00)||(auxch==0x00)) // Control Packet Received
    {
      rch   = ((((int16_t)incomingPacket[1]<<8)+(int16_t)incomingPacket[2])-296);
      pch   = ((((int16_t)incomingPacket[3]<<8)+(int16_t)incomingPacket[4])-296);
      tch   = ((((int16_t)incomingPacket[5]<<8)+(int16_t)incomingPacket[6]))+60;
      ych   = ((((int16_t)incomingPacket[7]<<8)+(int16_t)incomingPacket[8])-296);
      rch = map(rch,-296,296,0,255);
      pch = map(pch,-296,296,0,255);
      tch = map(tch,0,660,0,500);
      ych = map(ych,-260,260,0,255);
    }

    rxcount++;
    current_pkt_cnt++;
   }
   if(rxcount>=RESP_CNT_MAX)
   {
    rxcount = 0;
    // send back a reply, to the IP address and port we got the packet from
    Udp.beginPacket(Udp.remoteIP(), 2399);
    replyPacket[0] = (unsigned char)(1);
    replyPacket[1] = (unsigned char)(120);//(abs(WiFi.RSSI()));
    replyPacket[2] = (unsigned char)(((float)ESP.getVcc()/22.82)-2.0);
    //replyPacket[2] = (unsigned char)(((float)analogRead(A0)/22.82)-2.0);//(48); // use this if you will read from the A0 pin
    Udp.write(replyPacket);
    Udp.endPacket();
   }
   #ifdef DEBUGLED    
   debug_flag = !debug_flag;
   digitalWrite(DEBUG_LED,debug_flag);
   #endif
   
   return 1; // Sucess
 }
 else
 {
  return 0; // fail
 }
}

void setup() {
  
  Serial.begin(115200);
  setup_hardware_wifi_ap();
  Serial.println("AP Setup done");
  EEPROM.begin(1024);   // Initlize EEPROM with 1K Bytes (Not useful in this code)
  pinMode(L_MOTOR, OUTPUT);
  pinMode(R_MOTOR, OUTPUT);
  analogWrite(L_MOTOR,0);
  analogWrite(R_MOTOR,0);
  delay(50);

  // UpdateServer
  const char* host = "esp8266-webupdate";
  MDNS.begin(host);
  httpUpdater.setup(&httpServer);
  httpServer.begin();
  MDNS.addService("http", "tcp", 80);
  Serial.printf("HTTPUpdateServer ready! Open http://%s.local/update in your browser\n", host);
  delay(500);    
    
}

void loop() {

  //UpdateServer
  httpServer.handleClient();
  MDNS.update();
  
  if(micros()-microsold >= PID_LOOP_US)
  {
    #ifdef DEBUGLED    
    digitalWrite(DEBUG_LED2,HIGH);
    #endif
    uint8_t m1h,m1l,m2h,m2l,mcmd;
    microsold = micros();
    check_rx_pkt(R_ch,P_ch,T_ch,Y_ch,AUX_ch);
    if((AUX_ch & 0x80) == 0x80) //if ARMED 
    {
      mot1_final = T_ch;
    }
    else  //NOT ARMED
    {
      mot1_final = 0;
    }
    if(WiFi.softAPgetStationNum() == 0)
    {
      AUX_ch=0x00;
      mot1_final = 0;
    }
    
    #ifdef DEBUGLED    
    digitalWrite(DEBUG_LED2,LOW);
    #endif

    /*
          Hier muss dann die Logic für die Motoren rein:
    */
      // Motor aus "disarmed"
      if (mot1_final == 0 ) {
        analogWrite(L_MOTOR,0);
        analogWrite(R_MOTOR,0);
      }

      // Motor an "armed"
      if (mot1_final > 0) {
        int16_t ruder_r = 0;
        int16_t ruder_l = 0;
        l_speed = mot1_final+l_calibrate;
        r_speed = mot1_final+r_calibrate;        

        if (R_ch > 128) {
          ruder_r = R_ch - 128;
          analogWrite(R_MOTOR,r_speed);
          analogWrite(L_MOTOR,l_speed+ruder_r);
        } else if (R_ch < 128) {
          ruder_l = 128 - R_ch;
          analogWrite(R_MOTOR,r_speed+ruder_l);
          analogWrite(L_MOTOR,l_speed);
        } else {
        analogWrite(L_MOTOR,l_speed);
        analogWrite(R_MOTOR,r_speed);
        }
      }
  

    #ifdef DEBUGSER  // debug message for check what IMU remote and PID doing
    Serial.print(mot1_final);         Serial.print('\t');
    Serial.print(AUX_ch);             Serial.print('\t');
    Serial.print(R_ch);               Serial.print('\t');
    Serial.print(P_ch);               Serial.print('\t');
    Serial.print(T_ch);               Serial.print('\t');
    Serial.print(Y_ch);               Serial.print("\r\n");
    #endif
       
    //disarm if no packet received for 3 seconds app closed accidently
    loop_count++; 
    if(loop_count>=500)
    {
      loop_count = 0;
      if(old_pkt_cnt == current_pkt_cnt)
      {
        AUX_ch = 0x00;
      }
      else
      {
        old_pkt_cnt = current_pkt_cnt;
      }  
    }
  }
}


// ========================= Setup Hardware and WiFi AP ===========================================
void setup_hardware_wifi_ap(void)
{
  // Set NodeMCU Wifi hostname based on chip mac address
  char chip_id[15];
  snprintf(chip_id, 15, "%04X", (uint16_t)(ESP.getChipId()));
  String APssid = "Wifi-Plane - " + String(chip_id);

  pinMode(DEBUG_LED,OUTPUT);
  pinMode(DEBUG_LED2,OUTPUT);
  digitalWrite(DEBUG_LED,HIGH);
  WiFi.mode(WIFI_AP);
  WiFi.softAPConfig(APlocal_IP, APgateway, APsubnet);
  //WiFi.softAP(APssid, APpassword);
  WiFi.softAP(APssid);
  Udp.begin(localUdpPort);
}

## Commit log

2024-07-26 Added files
    Added gerber files.
    Added STL files.
    Added pics
    [FluegelWinkel_3mm_Depron.stl, Motorblock_3mm_Depron.stl]
2024-08-18 Updated CAD
